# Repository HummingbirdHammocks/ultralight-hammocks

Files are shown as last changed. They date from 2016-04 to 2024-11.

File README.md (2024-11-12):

Hummingbird Hammocks
================
"[Hummingbird Hammocks](http://www.hummingbirdhammocks.com/) is an outdoor gear company that manufactures and sells hammocks and hammock related accessories."

Introduction
-------
These are the CAD files for Hummingbird Hammock's products and accessories, also included are a list of materials and instructions on assembly and usage.

We do not guarantee the accuracy of the DXF files for direct use on an automatic cutter (laser, cnc or otherwise.) Every cutter is slightly different and you might have to make adjustments in order for the files to meet your needs.

If you notice any problems with the files please submit them as issues.

License
-------

This work is licensed under the  Creative Commons Attribution-ShareAlike 4.0 International Public License. To view a copy of this license, visit <http://creativecommons.org/licenses/by-sa/4.0/deed.en_US> or send a letter to Creative Commons, 444 Castro Street, Suite 900, Mountain View, California, 94041, USA.

THESE DESIGNS ARE PROVIDED “AS IS”, WITHOUT WARRANTY OF ANY KIND, EXPRESS OR IMPLIED, INCLUDING BUT NOT LIMITED TO THE WARRANTIES OF MERCHANTABILITY, FITNESS FOR A PARTICULAR PURPOSE AND NONINFRINGEMENT. IN NO EVENT SHALL THE AUTHORS OR COPYRIGHT HOLDERS BE LIABLE FOR ANY CLAIM, DAMAGES OR OTHER LIABILITY, WHETHER IN AN ACTION OF CONTRACT, TORT OR OTHERWISE, ARISING FROM, OUT OF OR IN CONNECTION WITH THE HARDWARE OR THE USE OR OTHER DEALINGS IN THE HARDWARE.

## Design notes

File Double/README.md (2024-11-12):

# Double Hammock

The Hummingbird Hammocks Double Hammock is an ultralight hammock intended for camping, backpacking, or casual use. This model is best suited for extended trips, large individuals, or people looking for a very diagonal lay.

**Product Webpage:**
https://hummingbirdhammocks.com/products/double-hammock

## Table of Contents

- [Double Hammock](#double-hammock)
  - [Table of Contents](#table-of-contents)
  - [General Info](#general-info)
  - [Specifications](#specifications)
    - [Packed](#packed)
    - [In Use](#in-use)
  - [Features](#features)
  - [Transparency](#transparency)
    - [Materials](#materials)
    - [Manufacturing](#manufacturing)
  - [Usage](#usage)
  - [Care Instructions](#care-instructions)
  - [Open Source Hardware](#open-source-hardware)
  - [Support](#support)

## General Info

The Hummingbird Hammocks Ultralight Double Hammock is an ultralight hammock built for two. An additional 12 inches in length and 34 inches in width give you some extra room to stretch out. It holds 400 pounds and is designed by a FAA Certified Parachute Rigger. It brings parachute technology to the hammock industry for the first time. The Button Link attachment system contains no bulky or heavy metal parts, can be compressed into a small pack, and are as easy to assemble as buttoning your pants.

The perfect hammock to relax with another or to keep for yourself and hang like a king.

## Specifications

### Packed

- **Weight:** 10.2 oz (289 g)
- **Length:** 8 in (20 cm)
- **Width:** 5 in (13 cm)
- **Height:** 3 in (8 cm)

### In Use

- **Weight Rating:** 400 lbs (181 kg)
- **Length:** 116 in (295 cm)
- **Width:** 85 in (216 cm)

## Features

- Made in the USA
- Lock stitched With Military Spec Nylon Thread
- Built to FAA parachute rigging standards
- Extremely light weight
- Very low pack volume
- PIA-C-44378 T4 Certified Reserve Parachute Fabric
- 1500 lb Spectra Cord
- Certified Open Hardware US0095

## Transparency

### Materials

- PIA-C-44378 T4 Certified Ripstop Nylon (USA)
- Spectra - 1500 lb Spectra Cord (USA)
- Button - Black Nylon (China)
- Drawstring - Reflective Sleeved Dyneema (China)
- Cord Lock - Nylon (China)
- Thread - Military Spec Bonded Nylon (USA)

### Manufacturing

This product is cut and sewn in the USA.

## Usage

[Hammock Manual](../Manuals/HammockManual/README.md)

## Care Instructions

Please follow the care instructions found in our knowledgebase:
https://help.hummingbirdhammocks.com/hc/1694808310/27/care-instructions

## Open Source Hardware

OSHWA UID US000097
[OSHWA Certification Listing](https://certification.oshwa.org/us000097.html)

## Support

If you have any questions or need help with anything please contact us by creating an issue, emailing us at [help@hummingbirdhammocks.com](mailto:help@hummingbirdhammocks.com), or open a [support ticket](https://help.hummingbirdhammocks.com/help/1694808310)

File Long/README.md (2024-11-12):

# Long Hammock

The Hummingbird Hammocks Long Hammock is an ultralight hammock intended for camping, backpacking, or casual use. This model is best suited for extended trips, large individuals, or people looking for a very diagonal lay.

**Product Webpage:**
https://hummingbirdhammocks.com/products/long-hammock

## Table of Contents

- [Long Hammock](#long-hammock)
  - [Table of Contents](#table-of-contents)
  - [General Info](#general-info)
  - [Specifications](#specifications)
    - [Packed](#packed)
    - [In Use](#in-use)
  - [Features](#features)
  - [Transparency](#transparency)
    - [Materials](#materials)
    - [Manufacturing](#manufacturing)
  - [Usage](#usage)
  - [Care Instructions](#care-instructions)
  - [Open Source Hardware](#open-source-hardware)
  - [Support](#support)

## General Info

The Hummingbird Hammocks Ultralight Long Hammock is longer version of our Single+ Hammock. Measuring nearly 11 feet long and 63 inches wide, this hammock will allow you to achieve the deepest of deep diagonal lays. Those among you blessed with exceptional height can rest without fear of your feet sticking out. It holds 350 pounds and is designed by an FAA Certified Parachute Rigger. The Button Link attachment system contains no bulky or heavy metal parts, can be compressed into a small pack, and are as easy to assemble as buttoning your pants.

No matter how tall, your head will go from brushing the clouds to resting easy in the roomy Long Hammock.

## Specifications

### Packed

- **Weight:** 8.2 oz (232 g)
- **Length:** 8 in (20 cm)
- **Width:** 5 in (13 cm)
- **Height:** 3 in (8 cm)

### In Use

- **Weight Rating:** 350 lbs (159 kg)
- **Length:** 128 in (325 cm)
- **Width:** 63 in (160 cm)

## Features

- Made in the USA
- Lock stitched With Military Spec Nylon Thread
- Built to FAA parachute rigging standards
- Extremely light weight
- Very low pack volume
- PIA-C-44378 T4 Certified Reserve Parachute Fabric
- 1500 lb Spectra Cord
- Certified Open Hardware US0095

## Transparency

### Materials

- PIA-C-44378 T4 Certified Ripstop Nylon (USA)
- Spectra - 1500 lb Spectra Cord (USA)
- Button - Black Nylon (China)
- Drawstring - Reflective Sleeved Dyneema (China)
- Cord Lock - Nylon (China)
- Thread - Military Spec Bonded Nylon (USA)

### Manufacturing

This product is cut and sewn in the USA.

## Usage

[Hammock Manual](../Manuals/HammockManual/README.md)

## Care Instructions

Please follow the care instructions found in our knowledgebase:
https://help.hummingbirdhammocks.com/hc/1694808310/27/care-instructions

## Open Source Hardware

OSHWA UID US002059
[OSHWA Certification Listing](https://certification.oshwa.org/us002059.html)

## Support

If you have any questions or need help with anything please contact us by creating an issue, emailing us at [help@hummingbirdhammocks.com](mailto:help@hummingbirdhammocks.com), or open a [support ticket](https://help.hummingbirdhammocks.com/help/1694808310)

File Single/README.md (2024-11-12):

# Single Hammock

The Hummingbird Hammocks Single Hammock is an ultralight hammock intended for camping, backpacking, or casual use. This model is best suited for short duration trips, campsite relaxation, smaller individuals, or serious ounce counters.

**Product Webpage:**
https://hummingbirdhammocks.com/products/single-hammock

## Table of Contents

- [Single Hammock](#single-hammock)
  - [Table of Contents](#table-of-contents)
  - [General Info](#general-info)
  - [Specifications](#specifications)
    - [Packed](#packed)
    - [In Use](#in-use)
  - [Features](#features)
  - [Transparency](#transparency)
    - [Materials](#materials)
    - [Manufacturing](#manufacturing)
  - [Usage](#usage)
  - [Care Instructions](#care-instructions)
  - [Open Source Hardware](#open-source-hardware)
  - [Support](#support)

## General Info

The Hummingbird Hammocks Ultralight Single Hammock is the lightest weight, smallest packing hammock on the market. It weighs less than a lemon and packs smaller than a coffee cup, holds up to 300 pounds, and is designed by an FAA Certified Parachute Rigger. It brings parachute technology to the hammock industry for the first time. The Button Link attachment system contains no bulky or heavy metal parts, can be compressed into a small pack, and are as easy to assemble as buttoning your pants.

This hammock is so light and tiny when packed, you’ll feel weird not bringing one everywhere you go.

## Specifications

### Packed

- **Weight:** 5.2 oz (147 g)
- **Length:** 4 in (10 cm)
- **Width:** 4 in (10 cm)
- **Height:** 2 in (5 cm)

### In Use

- **Weight Rating:** 300 lbs (136 kg)
- **Length:** 104 in (264 cm)
- **Width:** 47 in (119 cm)

## Features

- Made in the USA
- Lock stitched With Military Spec Nylon Thread
- Built to FAA parachute rigging standards
- Extremely light weight
- Very low pack volume
- PIA-C-44378 T4 Certified Reserve Parachute Fabric
- 1500 lb Spectra Cord
- Certified Open Hardware US0095

## Transparency

### Materials

- PIA-C-44378 T4 Certified Ripstop Nylon (USA)
- Spectra - 1500 lb Spectra Cord (USA)
- Button - Black Nylon (China)
- Drawstring - Reflective Sleeved Dyneema (China)
- Cord Lock - Nylon (China)
- Thread - Military Spec Bonded Nylon (USA)

### Manufacturing

This product is cut and sewn in the USA.

## Usage

[Hammock Manual](../Manuals/HammockManual/README.md)

## Care Instructions

Please follow the care instructions found in our knowledgebase:
https://help.hummingbirdhammocks.com/hc/1694808310/27/care-instructions

## Open Source Hardware

OSHWA UID US000095
[OSHWA Certification Listing](https://certification.oshwa.org/us000095.html)

## Support

If you have any questions or need help with anything please contact us by creating an issue, emailing us at [help@hummingbirdhammocks.com](mailto:help@hummingbirdhammocks.com), or open a [support ticket](https://help.hummingbirdhammocks.com/help/1694808310)

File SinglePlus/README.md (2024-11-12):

# Single Plus Hammock

The Hummingbird Hammocks Single Plus Hammock is an ultralight hammock intended for camping, backpacking, or casual use. This model is best suited for overnight trips for uses of any size.

**Product Webpage:**
https://hummingbirdhammocks.com/products/single-plus-hammock

## Table of Contents

- [Single Plus Hammock](#single-plus-hammock)
  - [Table of Contents](#table-of-contents)
  - [General Info](#general-info)
  - [Specifications](#specifications)
    - [Packed](#packed)
    - [In Use](#in-use)
  - [Features](#features)
  - [Transparency](#transparency)
    - [Materials](#materials)
    - [Manufacturing](#manufacturing)
  - [Usage](#usage)
  - [Care Instructions](#care-instructions)
  - [Open Source Hardware](#open-source-hardware)
  - [Support](#support)

## General Info

The Hummingbird Hammocks Ultralight Single+ Hammock is a bit larger version of the Single Hammock. An additional 12 inches in length and 14 inches in width give you some extra room to stretch out. It holds 350 pounds and is designed by an FAA Certified Parachute Rigger. It brings parachute technology to the hammock industry for the first time. The Button Link attachment system contains no bulky or heavy metal parts, can be compressed into a small pack, and are as easy to assemble as buttoning your pants.

This hammock has your back when you need some extra room on long trips or extra space for all that awesome gear.

## Specifications

### Packed

- **Weight:** 7.6 oz (215 g)
- **Length:** 6 in (15 cm)
- **Width:** 4 in (10 cm)
- **Height:** 2 in (5 cm)

### In Use

- **Weight Rating:** 350 lbs (159 kg)
- **Length:** 116 in (295 cm)
- **Width:** 63 in (160 cm)

## Features

- Made in the USA
- Lock stitched With Military Spec Nylon Thread
- Built to FAA parachute rigging standards
- Extremely light weight
- Very low pack volume
- PIA-C-44378 T4 Certified Reserve Parachute Fabric
- 1500 lb Spectra Cord
- Certified Open Hardware US0095

## Transparency

### Materials

- PIA-C-44378 T4 Certified Ripstop Nylon (USA)
- Spectra - 1500 lb Spectra Cord (USA)
- Button - Black Nylon (China)
- Drawstring - Reflective Sleeved Dyneema (China)
- Cord Lock - Nylon (China)
- Thread - Military Spec Bonded Nylon (USA)

### Manufacturing

This product is cut and sewn in the USA.

## Usage

[Hammock Manual](../Manuals/HammockManual/README.md)

## Care Instructions

Please follow the care instructions found in our knowledgebase:
https://help.hummingbirdhammocks.com/hc/1694808310/27/care-instructions

## Open Source Hardware

OSHWA UID US000096
[OSHWA Certification Listing](https://certification.oshwa.org/us000096.html)

## Support

If you have any questions or need help with anything please contact us by creating an issue, emailing us at [help@hummingbirdhammocks.com](mailto:help@hummingbirdhammocks.com), or open a [support ticket](https://help.hummingbirdhammocks.com/help/1694808310)

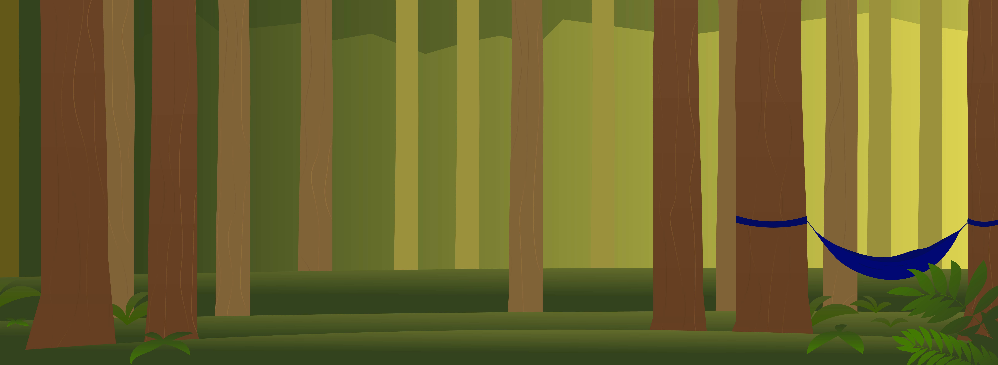
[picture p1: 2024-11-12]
Long/Graphics/Backgrounds/Landscape_3 Long Hammock_2704x1520-01.jpg

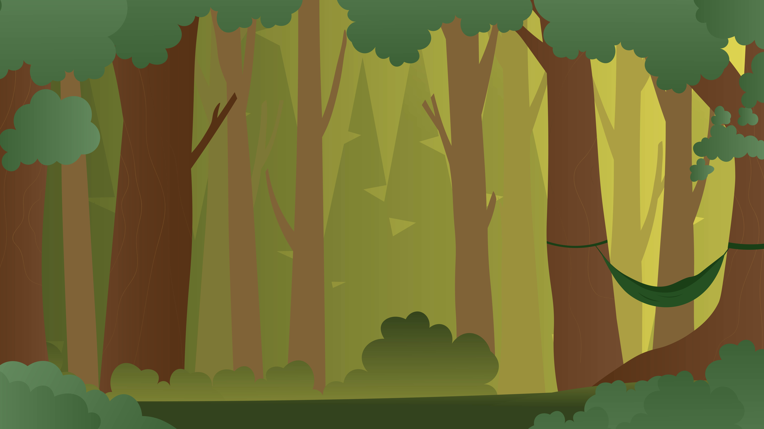
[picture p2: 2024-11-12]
SinglePlus/Graphics/Backgrounds/Landscape_2 Single_ Hammock_2 Single_ Hammock 2704x1520.jpg

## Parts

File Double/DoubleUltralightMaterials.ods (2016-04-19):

Hummingbird Hammocks Double Hammock Materials
Material | Use/ Location | Quantity
PIA-C-44378 fabric (also referred to as F111 or Exacta-Chute Material) | Main hammock fabric | 125.5 in
Type IIA Sleeving (or similar) | Stuff sack drawstring | 18 in
Cord lock | Stuff sack drawstring | 1
Size 46 bonded nylon thread (Mil-Spec A-A-59826 Type III Class B) | Load bearing stitching on hammock ends and between panels | ~1608 in
Size 33 bonded nylon thread | Non-load bearing stitching on sides of hammock | ~464 in
Heavy duty nylon overlock thread | Overlocking on stuff sack | ~38 in
Hummingbird Hammocks button link end loop | Loop around gathered end of hammock | 2

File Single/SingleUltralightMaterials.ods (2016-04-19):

Hummingbird Hammocks Single Hammock Materials
Material/ Part | Use/ Location | Quantity
PIA-C-44378 fabric (also referred to as F111 or Exacta-Chute Material) | Main hammock fabric | 108 in
Type IIA Sleeving (or similar) | Stuff sack drawstring | 14 in
Cord lock | Stuff sack drawstring | 1
Size 46 bonded nylon thread (Mil-Spec A-A-59826 Type III Class B) | Load bearing stitching on hammock ends | ~376 in
Size 33 bonded nylon thread | Non-load bearing stitching on sides of hammock | ~416 in
Heavy duty nylon overlock thread | Overlocking on stuff sack | ~28 in
Hummingbird Hammocks button link end loop | Loop around gathered end of hammock | 2

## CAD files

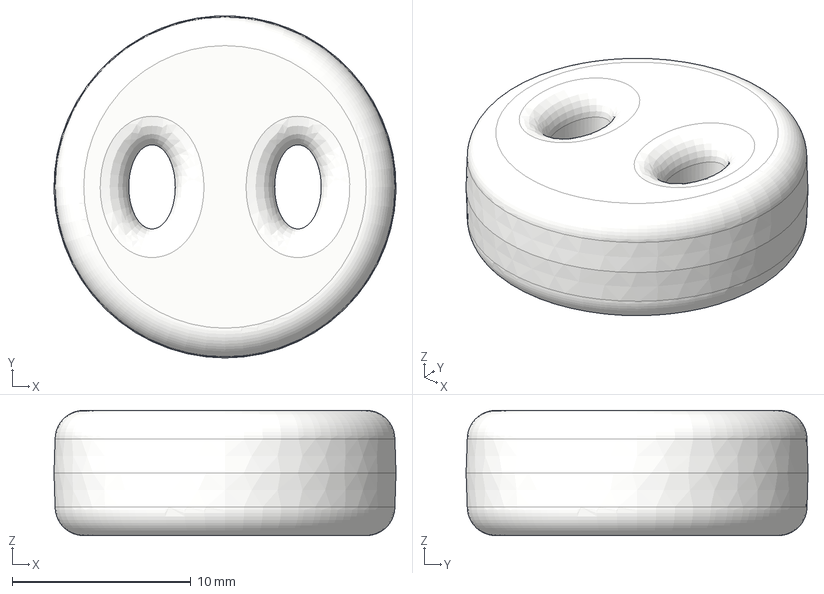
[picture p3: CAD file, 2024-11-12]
Parts/ButtonHardware/ButtonV6.step
19.1 x 19.1 x 7.00 mm

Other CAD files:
Double/DoubleUltralight.dxf
Parts/ButtonLinks/ButtonLink.dxf
Single/SingleUltralight.dxf
Parts/ButtonHardware/button.stl
Double/DoubleUltralight.dwg
Long/LongUltralight.dwg
Parts/ButtonHardware/ButtonV6.iges
Parts/ButtonLinks/ButtonLink.dwg
Single/SingleUltralight.dwg
SinglePlus/SinglePlusUltralight.dwg

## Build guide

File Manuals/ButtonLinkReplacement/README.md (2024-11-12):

# Hammock Button Link Replacement Guide

Please follow this guide to replace damaged or worn out Button Links or simply readajust your improperly connected Button Link.

Remove the old Button Link by pulling the white spectra cord that is looped around the gathered hammock fabric and undoing the larks head knot. Pull the Button Link from the channel of the hammock fabric.

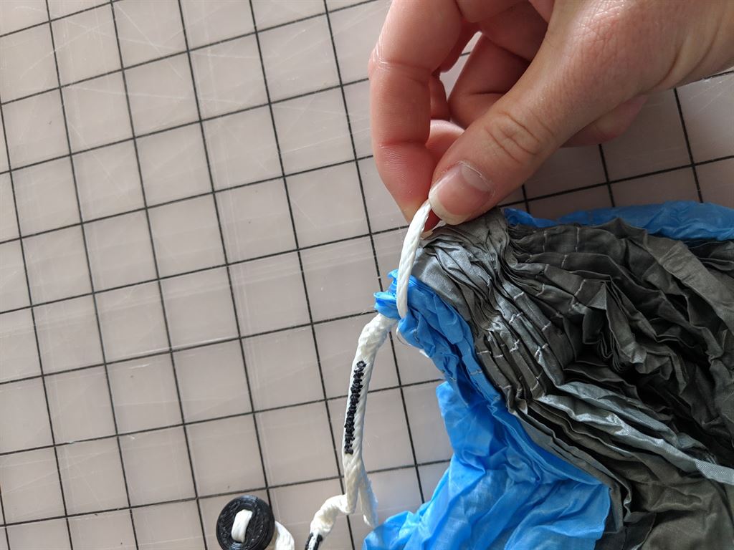
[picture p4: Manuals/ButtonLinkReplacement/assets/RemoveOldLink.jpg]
Remove Old Link


Feed the new Button Link through the same channel. It does not matter which direction the Button Link goes through.

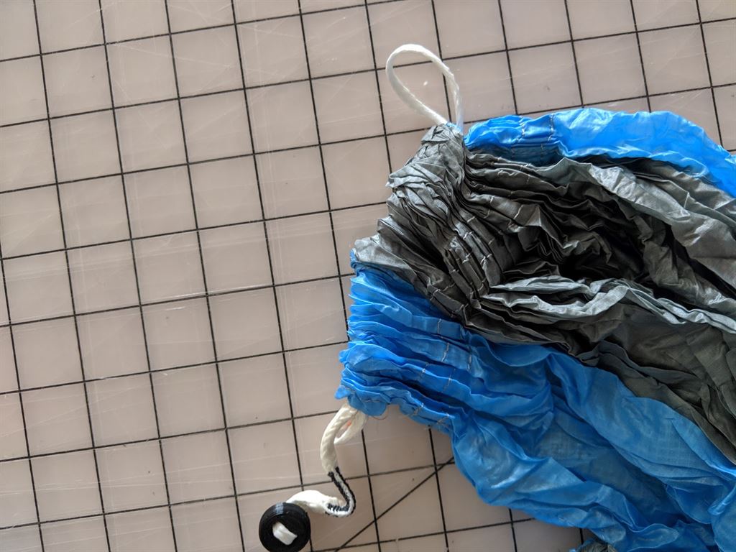
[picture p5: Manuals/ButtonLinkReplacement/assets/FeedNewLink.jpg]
Feed New Link


Create a new larks head knot by feeding the button at one end through the large loop at the other end.

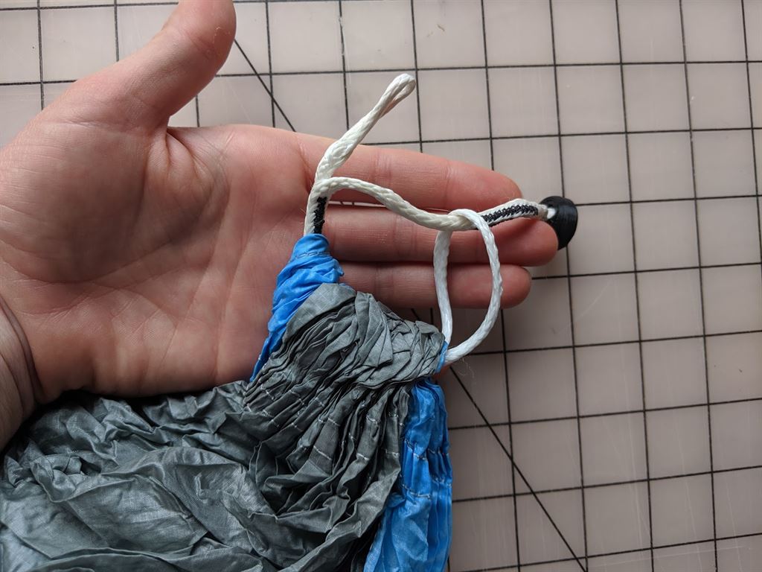
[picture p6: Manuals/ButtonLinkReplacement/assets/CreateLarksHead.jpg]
Create Larks Head


With one hand, pull the gathered hammock fabric tight so that no excess fabric is tied with the spectra cord.

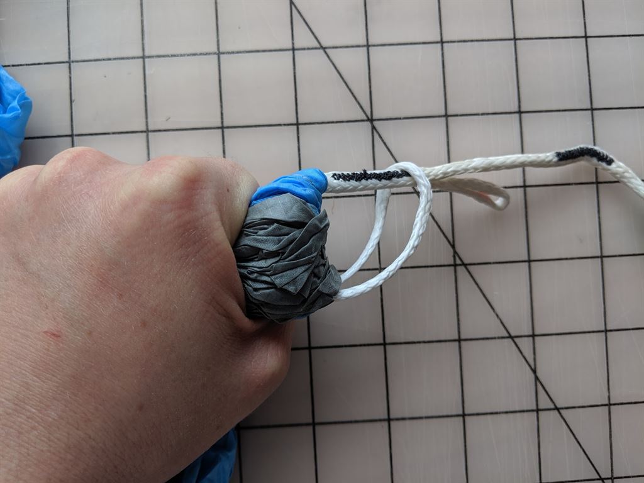
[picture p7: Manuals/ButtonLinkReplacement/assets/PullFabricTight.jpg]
Pull Fabric Tight


With the other hand, slip the loop end of the Button Link around the gathered hammock fabric, making sure the cord is not in contact with itself.

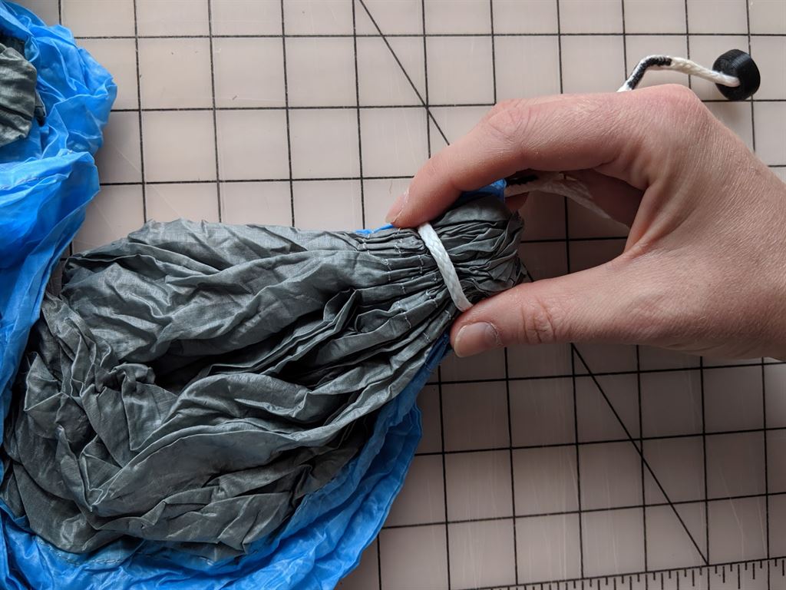
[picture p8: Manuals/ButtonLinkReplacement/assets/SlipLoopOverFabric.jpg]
Slip Loop Over Fabric


Now, pull the button end of the Button Link so that the larks head knot tightens around the hammock fabric. The knot will be more secure when you have put your weight in the hammock.

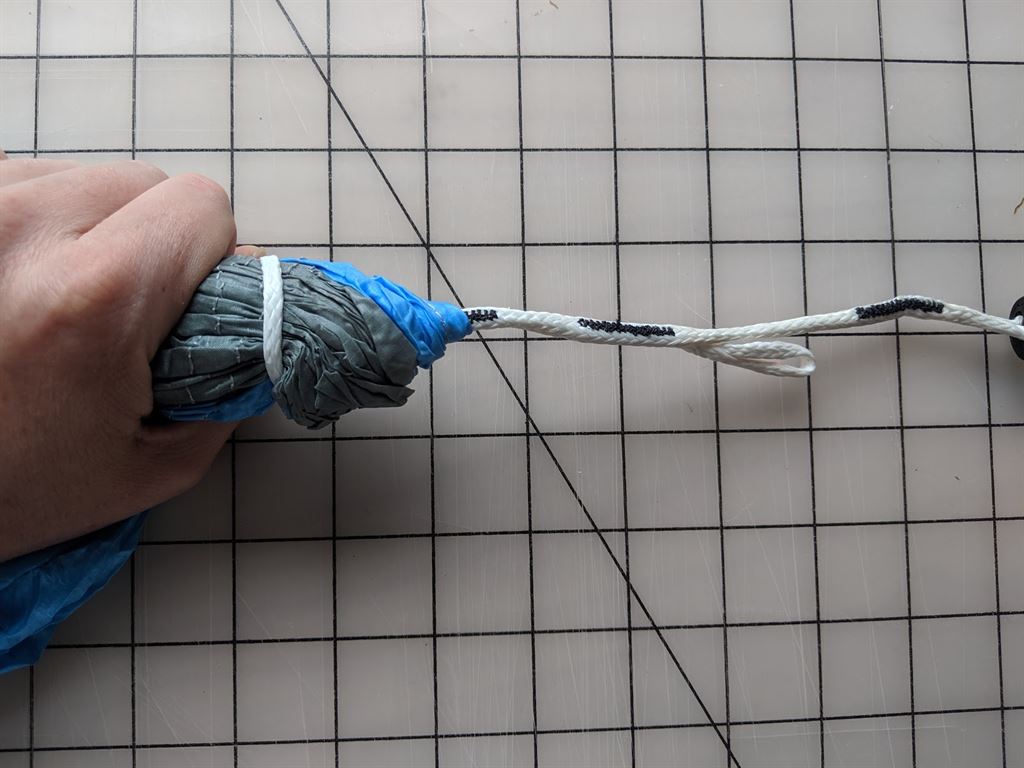
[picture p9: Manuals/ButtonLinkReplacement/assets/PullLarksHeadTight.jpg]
Pull Larks Head Tight


Your spectra cord should NOT be contacting itself. If your cord is not wrapped around the hammock fabric, the stitching of the fabric will wear out more quickly.

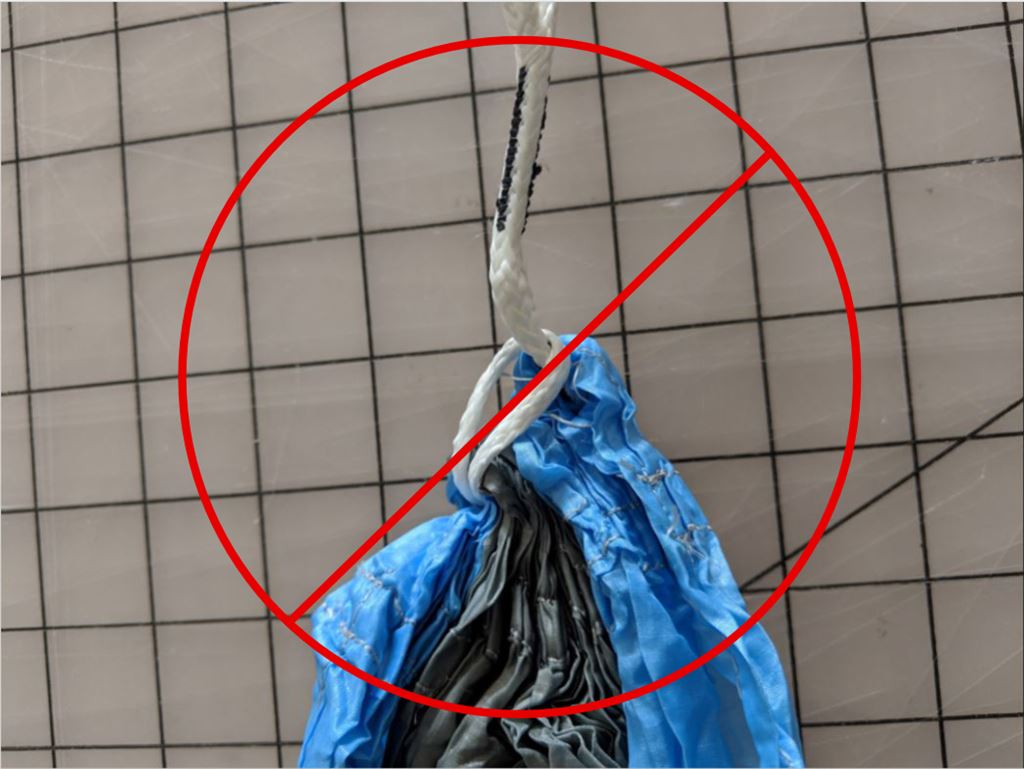
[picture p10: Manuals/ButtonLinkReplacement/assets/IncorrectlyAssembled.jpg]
Incorrectly Assembled


Please be sure your Button Link is properly connected before each use.

Happy hanging!

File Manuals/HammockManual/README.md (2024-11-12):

# Hammock Manual

## VIDEO GUIDE

https://youtu.be/JqwfwNxZbc0

## PARTS

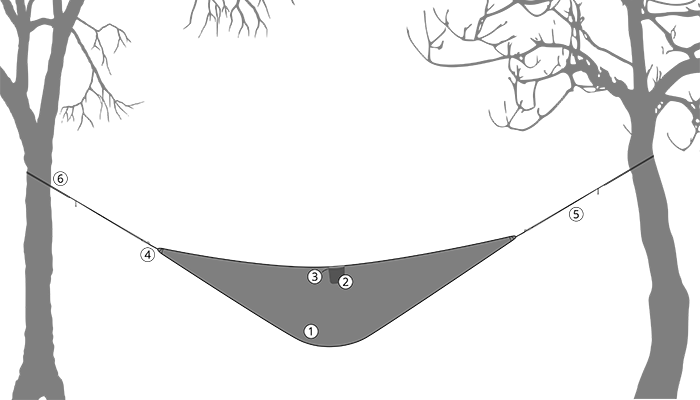
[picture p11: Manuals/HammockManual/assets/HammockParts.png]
Hammock Parts


1. Hammock Body
2. Stuff Sack
3. Drawstring
4. Button Link
5. Whoopie Sling
6. Tree Strap

## CHECK

Look for signs of wear, damage, loose stitching, or discoloration. If you find anything that would indicate a potential failure, please contact us before using the hammock and we will provide advice on how to proceed.

Never exceed the maximum rated weight for each hammock or tree straps. These weight ratings exist to protect the equipment and the user, and are the maximum safe weight the hammock will hold. The maximum weight an entire system will hold is dictated by the weakest piece of equipment, for example if the tree straps are rated to 400 lbs and the hammock is rated to 300 lbs, the weight supported by the entire system must not exceed 300 lbs.

Ensure there are no sharp objects in your back pockets or on your pants, any small rocks or other debris in the hammock that may damage it. This is the most common reason for a failure.

## LOCATION

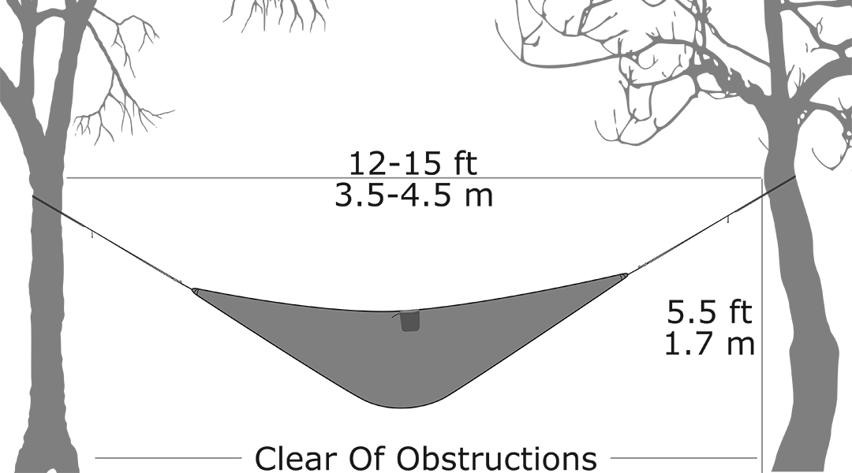
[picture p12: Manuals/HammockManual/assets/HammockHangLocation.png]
Hammock Hang Location


Look for a spot with two sturdy trees (or other objects to attach to) that are about 12 to 15 feet apart. Be sure the trees are thick enough and healthy enough to hang from, we recommend at least 8 inches in diameter. One of the major advantages of hammock camping is not having to worry about finding a clear and flat spot for a tent. However we still recommend not setting up over sharp rocks or at the edge of a cliff.

## STRAPS

Attach the webbing end of the tree straps to the trees by wrapping them around the trunk and passing the whoopie sling end of the strap through the small sewn webbing loop. Pull the extra slack out of the webbing loop created around the tree, and snug them up about 6 feet from the ground.

Adjustment to the whoopie sling must be done while there is no weight on the hammock or straps. To adjust the length of the whoopie slings so they are shorter, simply pull the single string extending from the finger trapped section with the single knot on the end. To extend the whoopie sling, hold onto the knot on the loop section just before the fingertrap section and then extend the loop by pulling gently on the opposing side of the loop. Holding the knot during this process relives strain on the fingertrap to allow movement and lengthening of the whoopie sling.

Adjust the whoopie slings out to allow enough length to attach the hammock, leave some extra slack at this point to make it easier to assemble.

## ATTACH

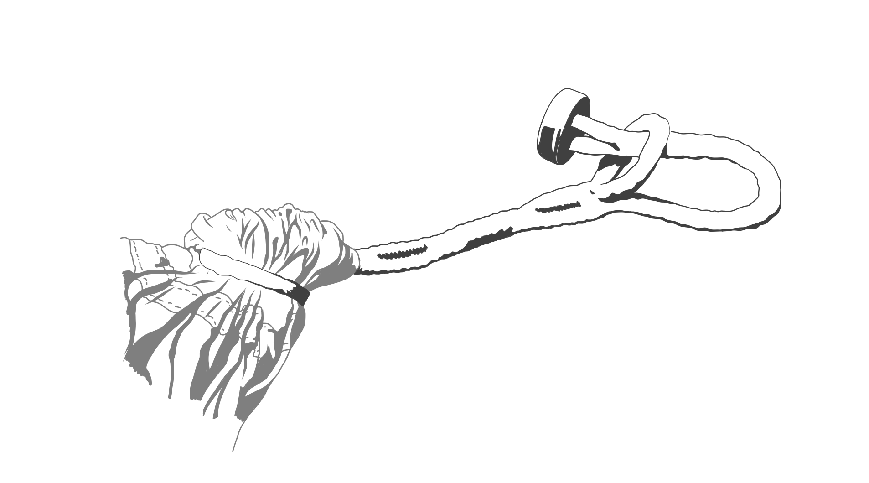
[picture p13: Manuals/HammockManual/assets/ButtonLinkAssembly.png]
Button Link Assembly


Remove hammock from stuff sack, drape it over your shoulder or around your neck to keep it off the ground. Ensure the Button Links are properly attached; the white spectra cord should be tied around the hammock fabric, not resting on itself. For further explanation, please refer to the Button Link Replacement Guide. Using the button links, attach the hammock to the tree straps one end at a time. Pass the button end of the button link through the large loop end of the whoopie sling on the tree strap. Now pass the button through the small loop on the button link just as you would a typical garment button. This locks the button link closed and securely attaches the hammock to the tree straps.

## TENSION

Hammock Hang Tension
Adjust the whoopie slings, there will be some stretch when the hammock gets loaded with weight so make it a little tighter than the final intended hang angle. 30 degrees is typically considered an ideal hang angle, to achieve that angle we have found pulling the hammock so it hangs to an angle of 15 degrees before weight is added will ultimately be about right. You can determine 30 degrees by holding up your hand, thumb pointed to the sky and forefinger parallel to the horizon (pictured below). The angle from the tip of your thumb to the tip of your forefinger is approximately 30 degrees. Getting the right hang angle is trial and error and personal preference, have fun with it and see what works best for you!

## HANG

Check all components and connection points, ensure the tree straps are properly attached to the trees and the button links are correctly assembled. Carefully enter the hammock by sitting back into it like a chair, once the hammock is supporting weight check the hang angle again to be sure you are happy with it. Make any necessary adjustments or just lay back into the hammock and enjoy!

For sleeping or extended hammock sessions, we recommend laying in the hammock diagonally. This allows a flatter lie that is easier on the back, less prone to midnight wake ups and maximizes hammock surface area.

## UN-HANG

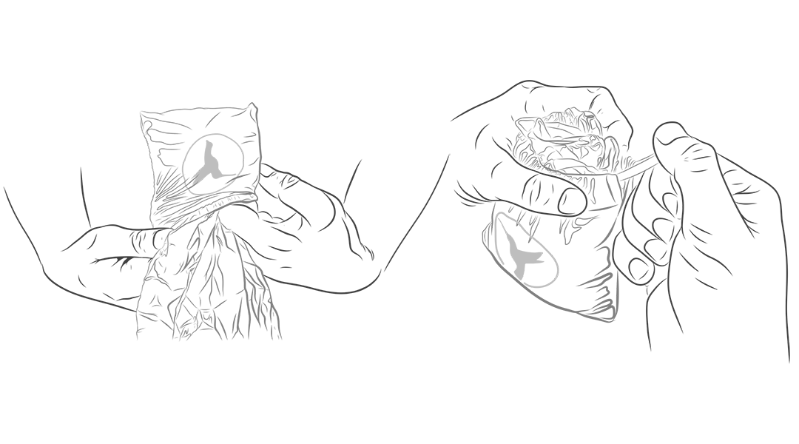
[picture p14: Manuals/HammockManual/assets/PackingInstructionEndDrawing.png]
Packing Instructions


To exit the hammock turn so you are sitting in it like a chair again. Lean forward and place your feet on the ground, lean forward and stand up. Now disassemble your hammock by reversing the setup steps.

Pack the hammock back into it’s stuff sack. This is easily accomplished by holding the bag upside down by the opening and using your fingers to push the hammock back into the bag. Pack as much of the hammock into the bottom of the bag as you can, this will ensure there is enough space in bag to fit the hammock. Pinch the top of the stuff sack as you pull the drawstring, and use the cord lock to secure it closed.

## WARNING

Do not leave the hammock or tree straps in direct sunlight. The UV light will degrade and weaken the nylon material over time.
Avoid stepping on the hammock, letting it drag on the ground or abrading it in any other way. This will weaken and damage the fabric.
Do not use solvents or soaps to clean the hammock, warm or room temperature water will remove most dirt and stains. If soap is needed, only use a very small amount of a very gentle cleaner like Woolite. Do not wash a hammock in a washing machine, gentle hand-wash only.
Dry your hammock in the shade, out of direct sunlight.
Do not pack the hammock up wet, this may result in mildew forming on the fabric.
Be responsible when selecting trees to hang from, they should be at least 8 inches in diameter and healthy enough to support the weight.
If not using Hummingbird Hammocks Tree Straps, please do not use ropes or thin webbing as this may damage the trees.
Don’t pull the hammock too tight when adjusting your tree straps, not only will this reduce the comfort of the hammock, but will also put undue stress on the tree straps and hammock and may result in hammock failure.
Do not bounce in the hammock, bouncing puts unnecessary stress on the hammock and tree straps.
Never exceed the maximum weight rating of any piece of your gear.
Ensure there are no sharp objects that will come in contact with the hammock or tree straps, this includes sticks, knives, sharp buttons on your pants, sharp rocks, or excessive dirt in the hammock.

## THANK YOU

Thank you for choosing Hummingbird Hammocks to be your adventure companion! We are honored to be a part of your kit, and appreciate how valuable your pack weight and volume is. We promise to take up as little space and weight as possible!

## CONTACT

If you have any questions, issues or want to provide us with some feedback, please contact us using one of the methods below:
https://help.hummingbirdhammocks.com/
help@hummingbirdhammocks.com

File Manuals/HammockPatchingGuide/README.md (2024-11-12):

# Hammock Patching Guide

How to repair damaged hammock fabric areas up to 3 inches long and 1 inch wide using the Tenacious Tape Flex Patch kit.

https://hummingbirdhammocks.com/products/tenacious-tape-flex-patches

1. Begin by cleaning the repair area with a damp rag to remove any dirt which may prevent a good bond. Trim any loose threads.
2. Cut out a patch with rounded corners that will overlap the repair area by at least 0.5'' in all directions.
3. Flatten out the fabric as much as possible, we like to some smooth objects like glass cups to gently hold the fabric around the damaged area.
4. Apply the Tenacious Tape patch over the rip, tear or hole.
5. Smooth out any bubbles and ensure the edges lay flat. The adhesive will reach full strength after 24 hours.
6. Repeat the above steps on the opposite side of the fabric.

https://youtu.be/yyRCcLi086w

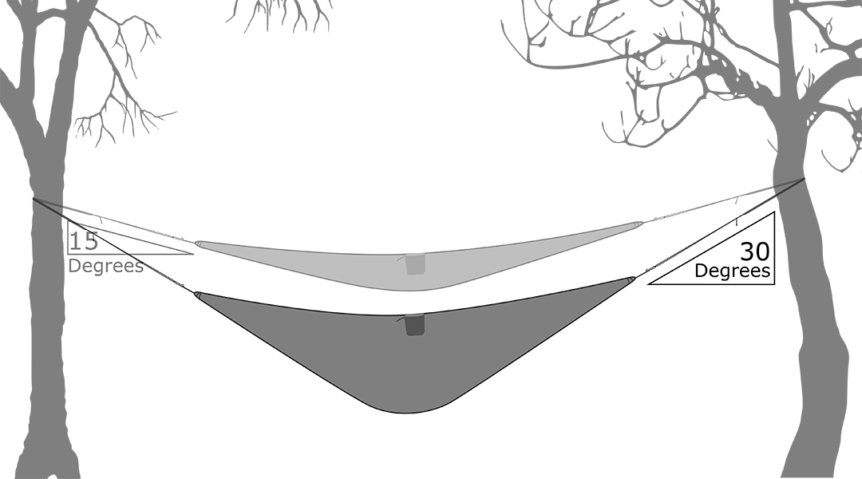
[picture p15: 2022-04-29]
Manuals/HammockManual/assets/HammockHangTension.png

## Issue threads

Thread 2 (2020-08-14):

Instructions for long hammock?

wammies, 2020-08-14:
Are there instructions for the long hammock somewhere? If not, would it be possible to add some? Thanks!

loidolt, 2020-08-14:
Thanks for checking out our designs!

Use and care instructions can be found here:
https://help.hummingbirdhammocks.com/support/solutions/articles/17000079196-hammock-manual

We don't currently have plans to release sewing/assembly instructions but if we change our mind they would be added to this repo.

Closed 2020-08-14.

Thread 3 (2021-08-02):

Pattern sewing instructions?

altsalt, 2021-08-02:
Hello, I have been following these designs for some time and am finally considering sewing one up myself out of non-lightweight materials for pre-modern festivals. However, I don't see any instructions in this repository akin to the ones [available for the mega hammock](https://github.com/HummingbirdHammocks/specialty-hammocks/tree/master/Mega). The response to #2 suggests that you won't be releasing these, but I figured as that was last year, it was worth checking again. However, if you won't be releasing them, would the instructions given for the mega generally be a good place to start? Are there any examples of how you suggest sewing up the ends for a strong connection? Thanks much for being an Open Hardware supporter!

loidolt, 2021-08-03:
Hi,

Thank you for following our designs and reaching out! I'm coming around to the idea of writing proper instructions, but it will take me a while to complete that either way.

In the meantime, the sewing is essentially the same as any other gathered end/ channel end hammock. This video seems to do a decent job showing how to sew one: [https://www.youtube.com/watch?v=4mg7TVhqNmQ](https://www.youtube.com/watch?v=4mg7TVhqNmQ).

The button links are slightly complex to make and sew, you would also need our custom nylon buttons. I recommend just ordering a set from us ([Replacement Button Link Set](https://hummingbirdhammocks.com/products/replacement-button-link-set)) or using an alternative method.

Be sure to use fabric and thread that is appropriate for the job. Size E bonded nylon thread thread will be sufficient and is reasonably easy to tension correctly in a home sewing machine.

altsalt, 2021-08-03:
In terms of fabric, I was actually contemplating using a canvas drop-cloth as the goal is to make a hammock that won't look out of place at a renaissance faire. I'm a bit confused about how the button system works. Does it feed through the end slots like a whoopie-sling and act like a carabiner?

Thank you for the links and further consideration for releasing instructions!

loidolt, 2021-08-06:
If you are using canvas you will need to adjust your stitching and thread choices to accommodate that fabric. I'm not very familiar with canvas and it's best practices so I can't really make any recommendations.

The button links serve to provide an attachment point to the gathered end of the hammock as well as carabiner type functionality. Your description is essentially accurate if you were to use an integrated whoopie sling hammock system. However, our button links will almost certainly not fit through the gathered end of a canvas hammock due to the extra bulk.

This guide from The Ultimate Hang provides some great examples of different attachment methods: [https://theultimatehang.com/2013/10/29/make-hammock-3-minutes/](https://theultimatehang.com/2013/10/29/make-hammock-3-minutes/)

altsalt, 2021-08-07:
Thanks!

Closed 2021-08-07.

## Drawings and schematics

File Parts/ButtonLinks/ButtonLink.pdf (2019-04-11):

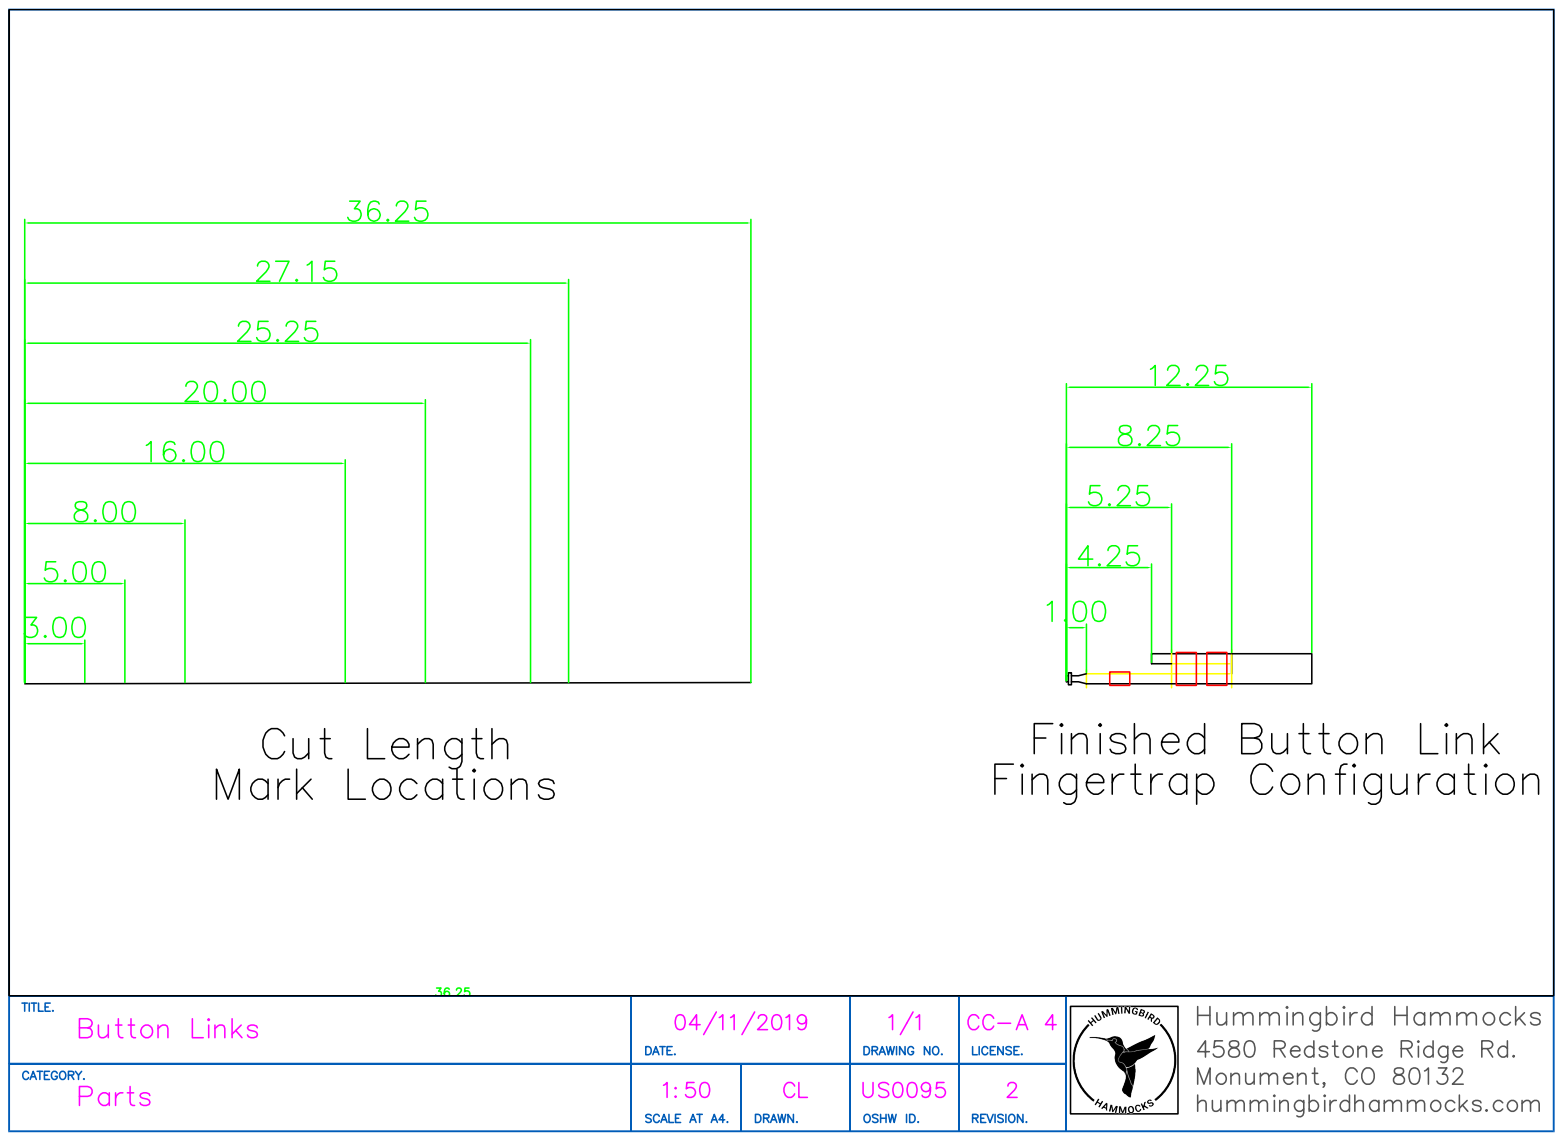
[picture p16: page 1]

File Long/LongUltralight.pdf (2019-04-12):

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

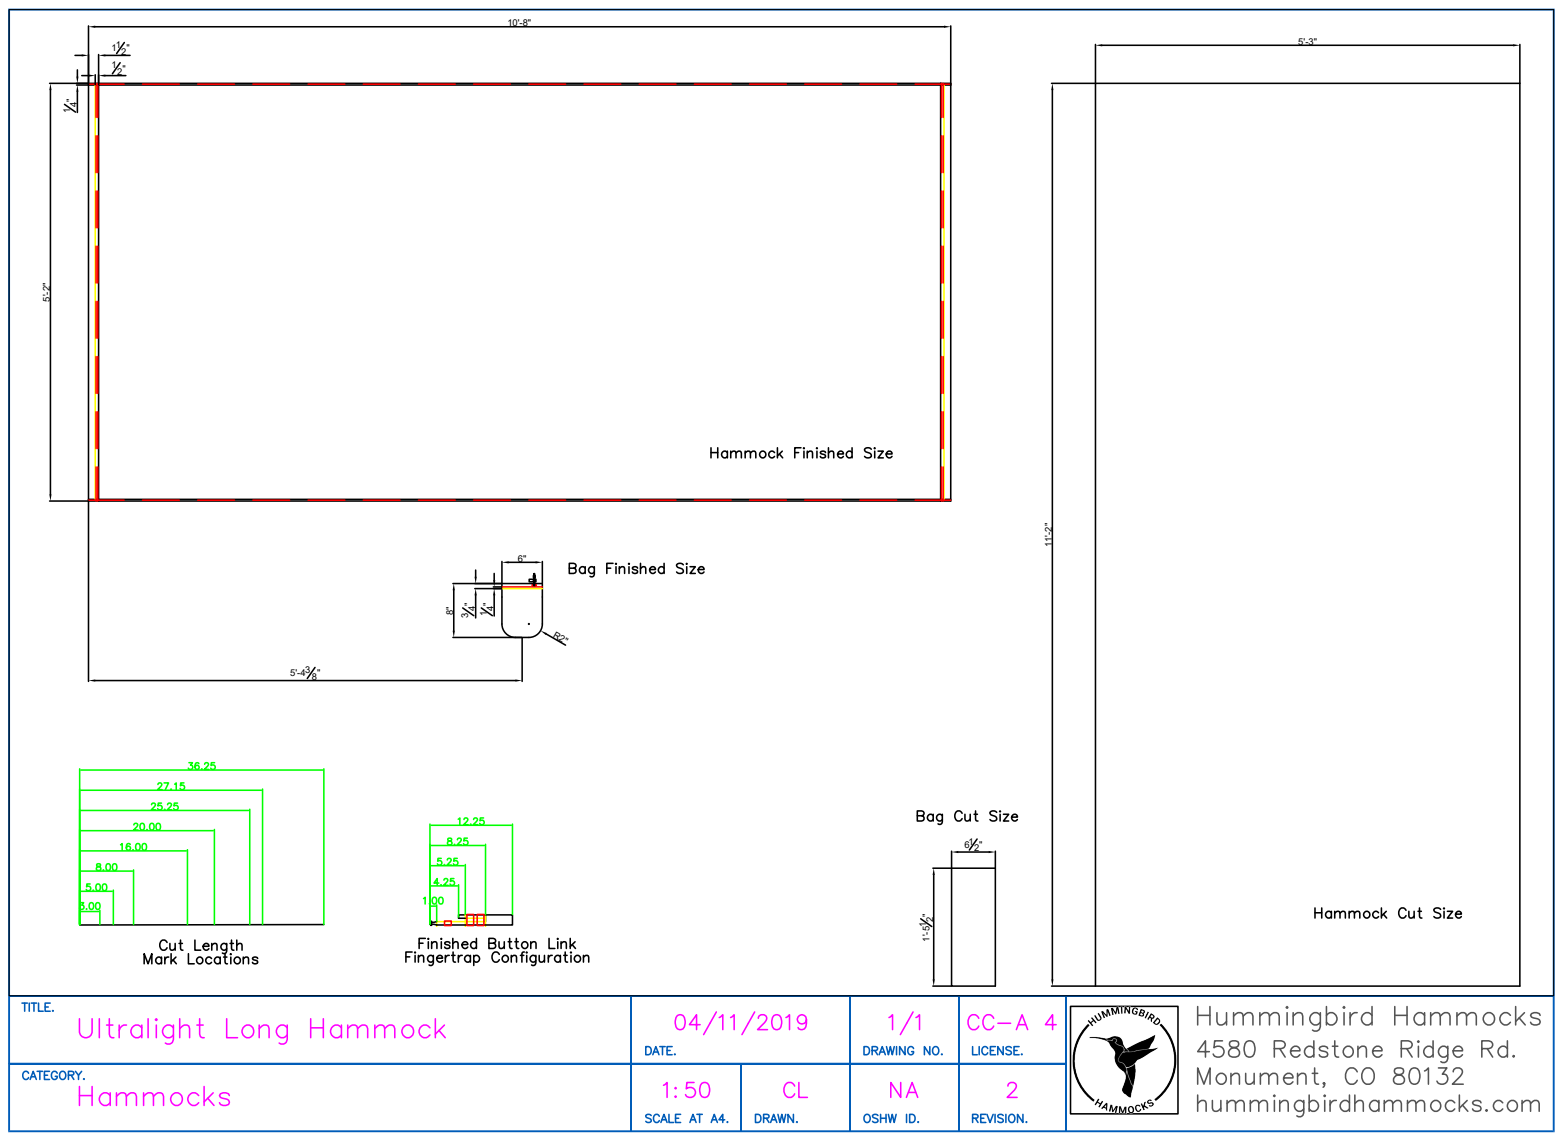
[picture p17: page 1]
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

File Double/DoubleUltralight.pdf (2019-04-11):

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

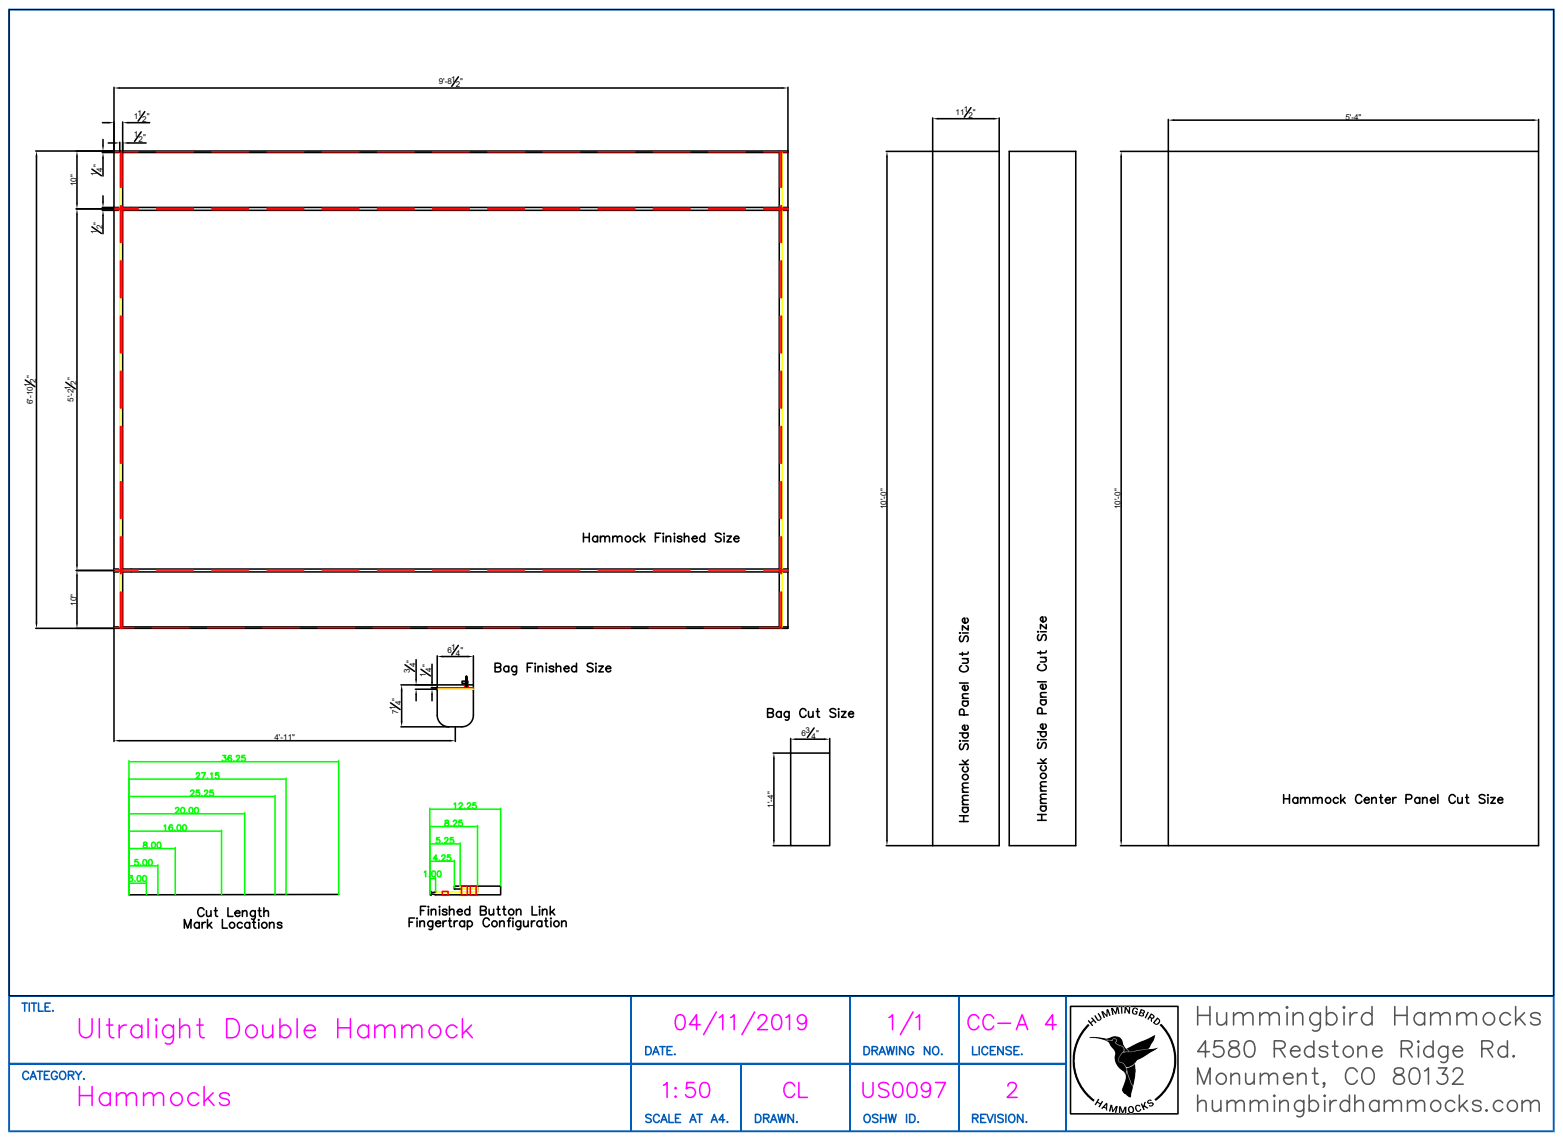
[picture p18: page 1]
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

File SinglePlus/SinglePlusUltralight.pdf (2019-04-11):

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

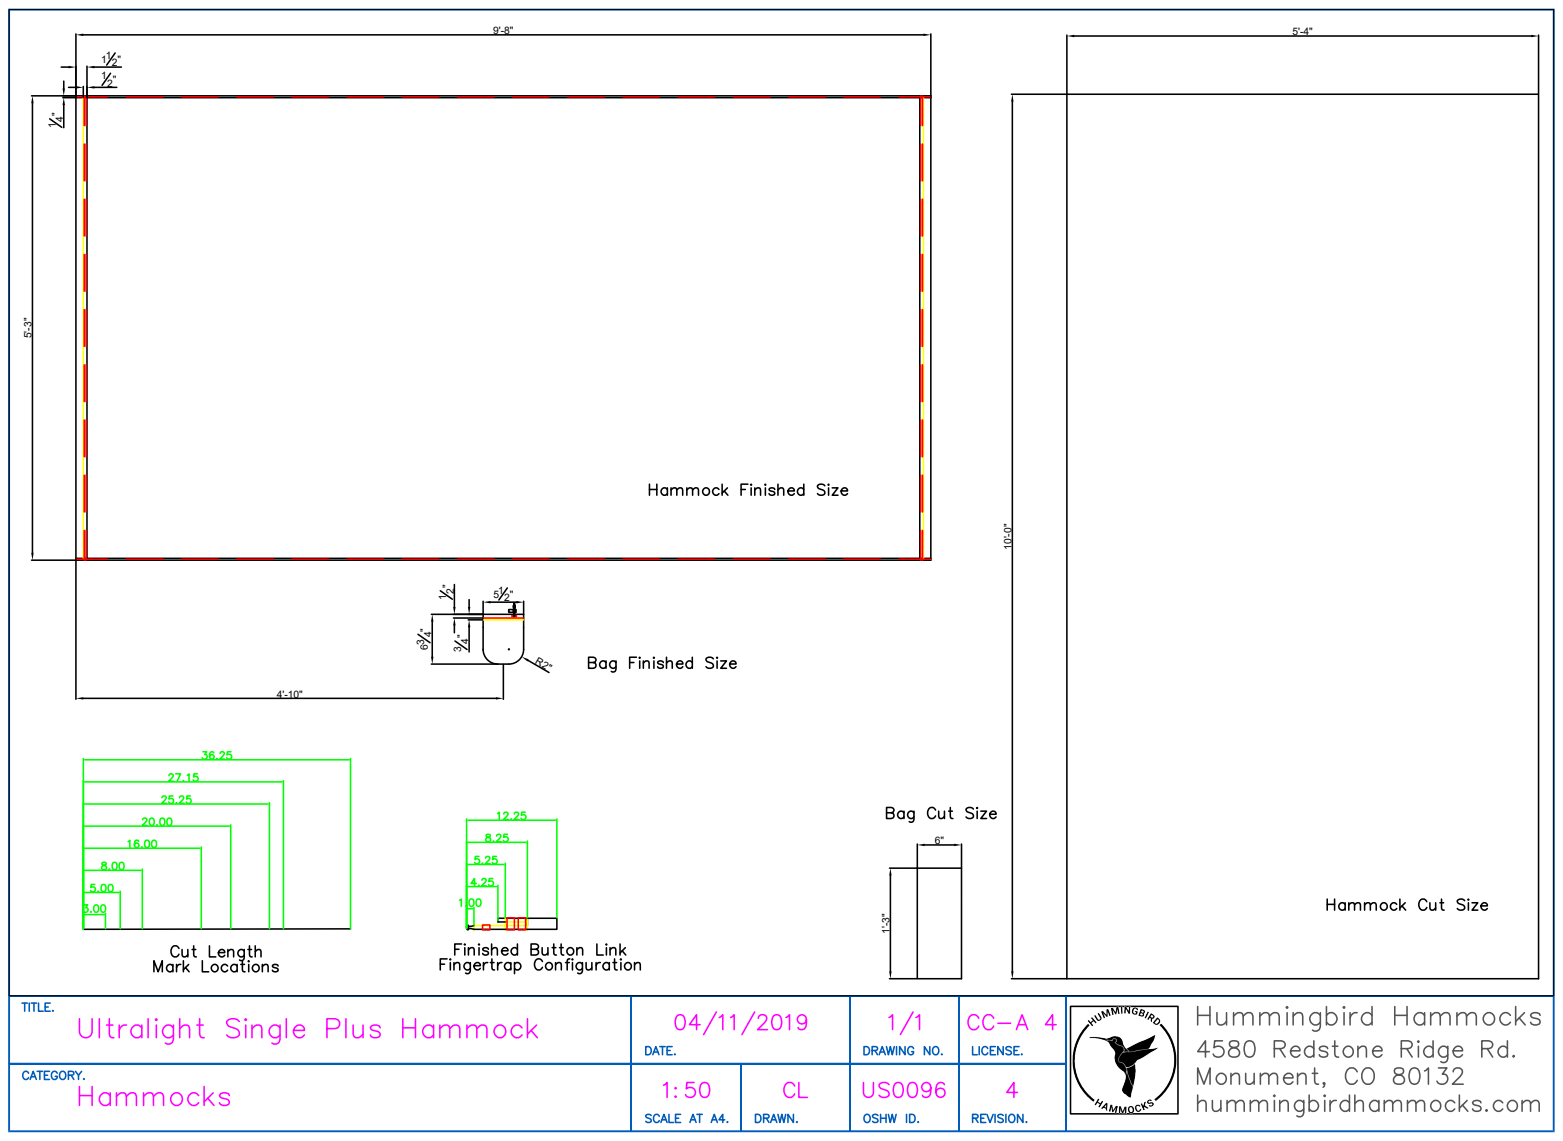
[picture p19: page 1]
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

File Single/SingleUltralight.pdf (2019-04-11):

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

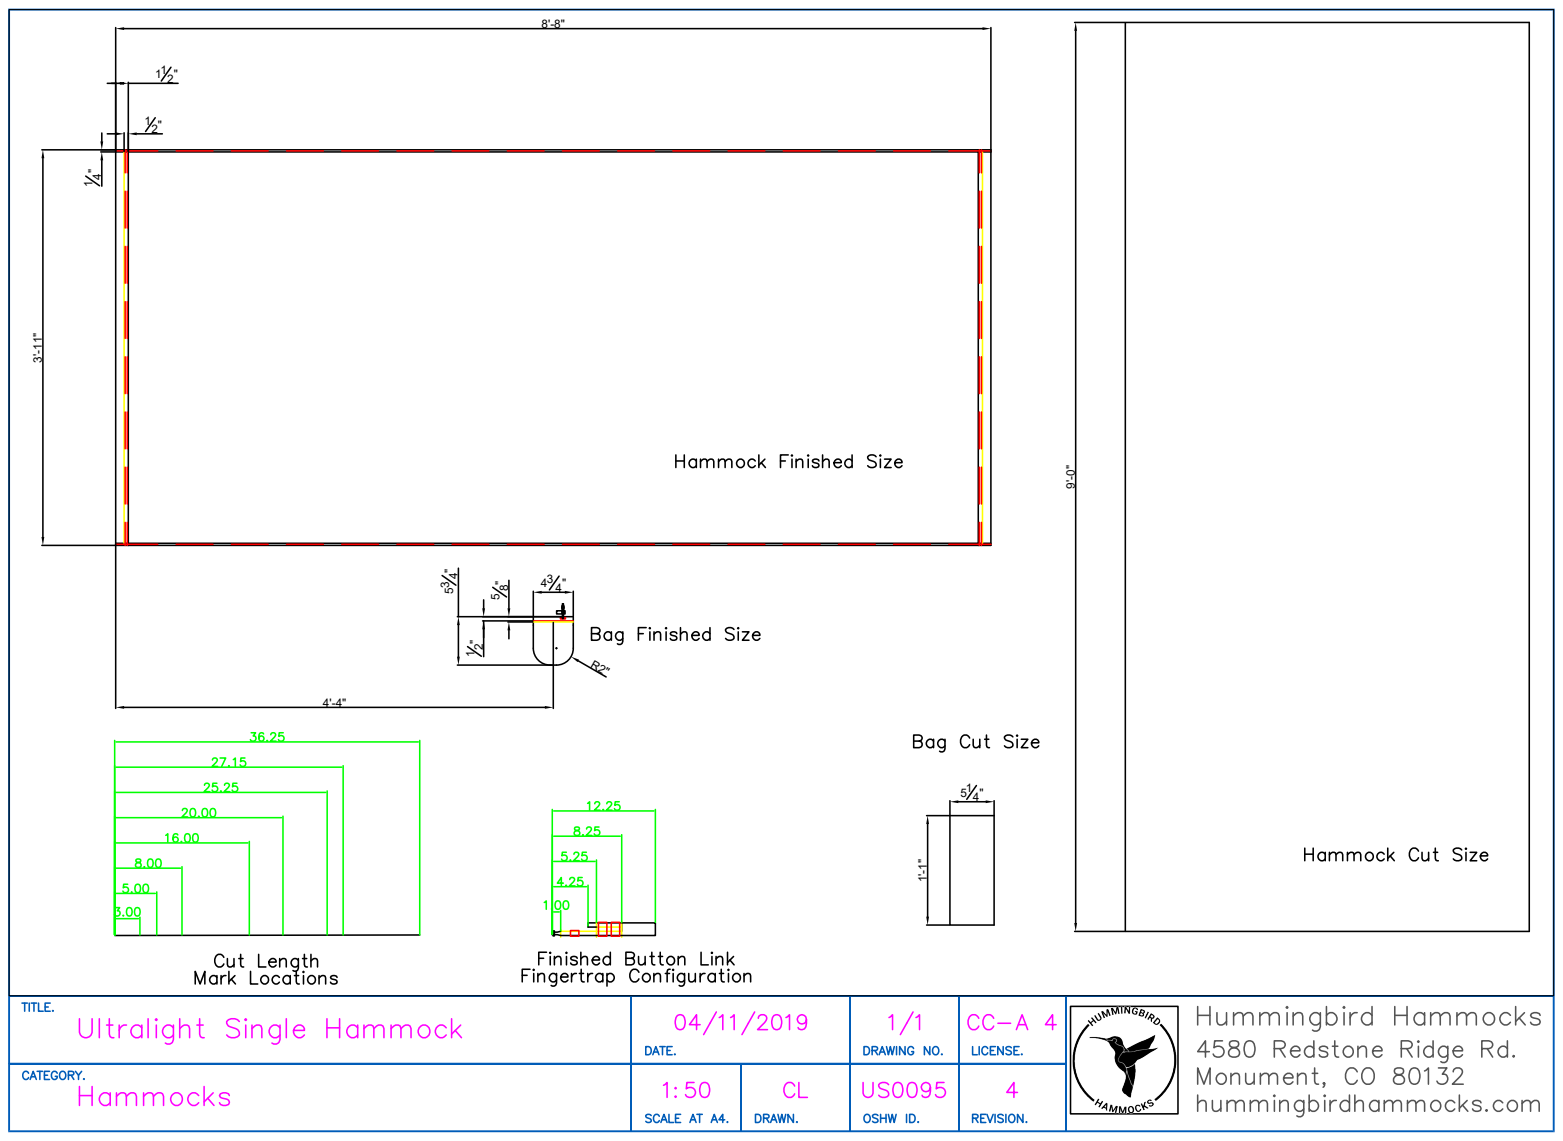
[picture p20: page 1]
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

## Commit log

2015-07-21 added folders for ultralight hammocks and dxf/pdf files
    [Double.dxf, Single+.dxf, Single.dxf]
2015-07-21 add materials list for single, single+ and double hammocks
    [doubleMaterials.ods, singleMaterials.ods, singlePlusMaterials.ods]
2015-07-23 add end loops and soft link carabiners to materials list
    [doubleMaterials.ods, singleMaterials.ods, singlePlusMaterials.ods]
2015-07-24 minor naming tweaks to prepare for non-ultralight hammocks
    [Double.dxf, Single+.dxf, Single.dxf]
2015-07-24 fix bag cut size
    [Single.dxf]
2015-07-24 more renaming
    [DoubleUltralight.dxf, DoubleUltralightMaterials.ods, SinglePlusUltralight.dxf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]
2015-07-25 overlaid finished size over cut size
    [SingleUltralight.dxf]
2015-07-25 undo previous change
    [SingleUltralight.dxf]
2015-07-31 add long ultralight hammock prototype folder/dxf
    [LongUltralight.dxf]
2015-08-21 Long hammock design finalized and bag sized from prototype
    [LongUltralight.dxf]
2015-08-26 Update changes to bag corner radius, remove pdf files
    PDF files removed due to the visibility issues for them and because they
    cant be edited
    [DoubleUltralight.dxf, SinglePlusUltralight.dxf, SingleUltralight.dxf]
2015-09-28 Add labels to all hammocks, brought back the pdf's
    [DoubleUltralight.dxf, LongUltralight.dxf, SinglePlusUltralight.dxf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]
2016-04-11 minor layer naming changes
    [DoubleUltralight.dxf, LongUltralight.dxf, SinglePlusUltralight.dxf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]
2016-04-19 update bag cut size
    [LongUltralight.dxf]
2016-04-19 update pdf to reflect new bag cut size
2016-04-19 updates to materials sheets
    update to all sheets to reflect new button links, add long hammock
    material sheet
    [DoubleUltralightMaterials.ods, LongUltralightMaterials.ods, SinglePlusUltralightMaterials.ods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]
2016-07-08 add .25" to bag length
    [SinglePlusUltralight.dxf]
2016-09-28 Add .5" to finished Single+ bag size
    [SinglePlusUltralight.dxf]
2016-09-28 Update bag length correctly
    [SinglePlusUltralight.dxf]
2018-01-18 Add Long Plus design files
    [LongPlusUltralight.dxf, LongUltralightMaterials.ods]
2018-01-18 Update material sheets
    [LongUltralightMaterials.ods]
2018-05-31 Correct Long+ finished width
    [LongPlusUltralight.dxf]
2018-05-31 Fix cut lengths
    [LongPlusUltralight.dxf, LongUltralight.dxf]
2019-04-11 Add Button Links, Update Single Hammock
    Shorten single hammock drawstring height
    [ButtonLink.dwg, ButtonLink.dxf, ButtonV6.iges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]
2019-04-11 Update Single+ Hammock design
    [SinglePlusUltralight.dwg, SinglePlusUltralight.dxf]
2019-04-11 Update Double Hammock design
    [DoubleUltralight.dwg, DoubleUltralight.dxf]
2019-04-12 Make bag 3/4" wider
    [LongUltralight.dwg, LongUltralight.dxf]
2022-04-29 Update gitignore
    [ButtonLink.dwg, ButtonLink.dxf, ButtonV6.iges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]
2022-04-29 Add button hardware
    [ButtonV6.iges, ButtonV6.step, button.stl]
2022-04-29 Add button links
    [ButtonLink.dwg, ButtonLink.dxf]
2022-04-29 Add button link replacement manual
2024-11-12 Update license to MIT
    [ButtonLink.dxf, ButtonV6.iges, ButtonV6.step]
